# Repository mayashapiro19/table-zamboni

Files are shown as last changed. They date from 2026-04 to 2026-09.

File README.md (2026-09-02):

# Table Zamboni

## Hardware Block Diagram
The image below shows a high-level block diagram of the hardware architecture.<br>
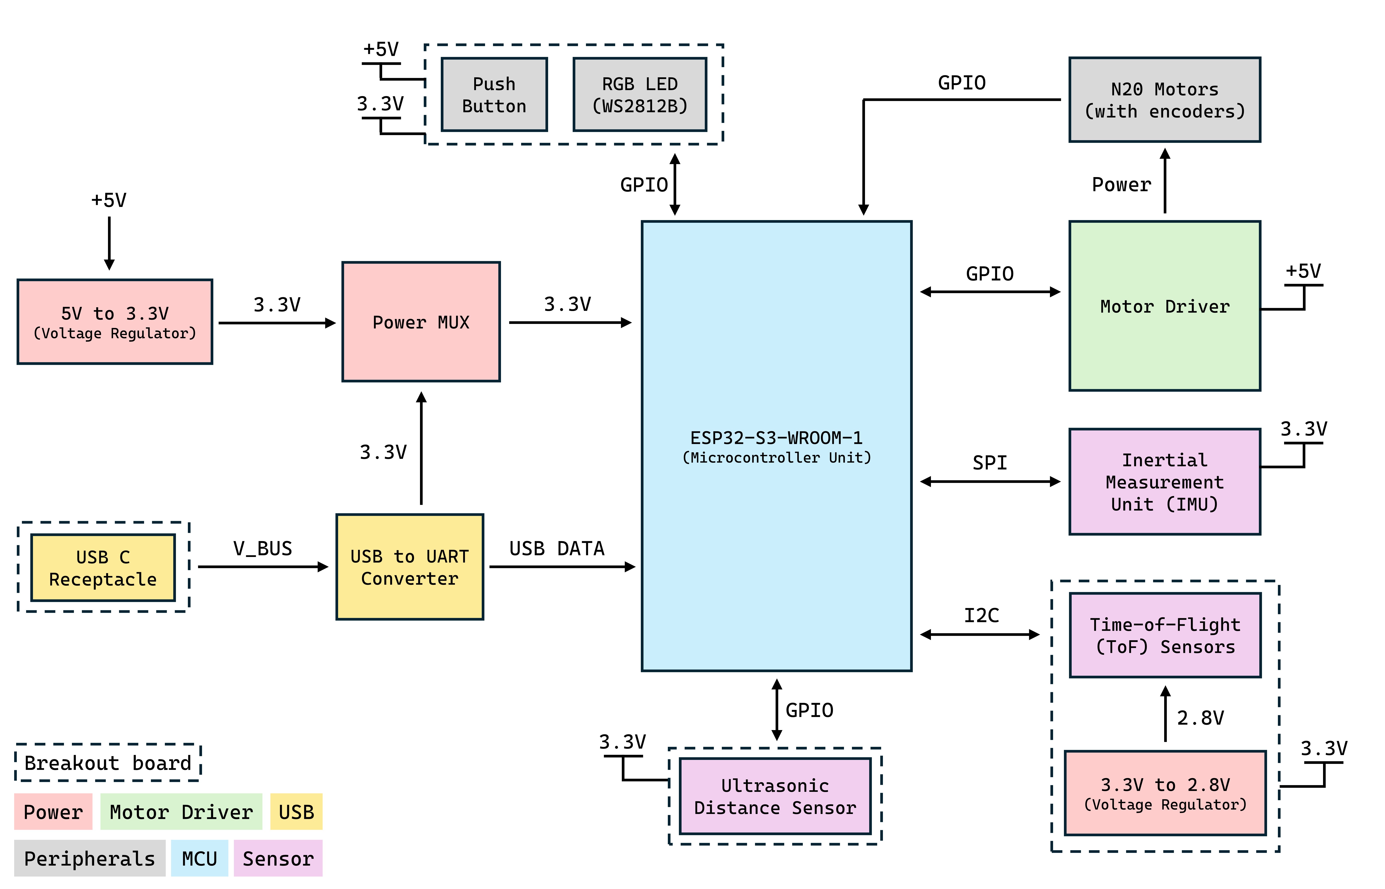
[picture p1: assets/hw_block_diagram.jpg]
Hardware Block Diagram


### Main PCB
The main PCB uses an ESP32-S3-WROOM-1-N8 module and includes power management circuitry, a USB to UART converter, motor driver, and an inertial measurement unit.

### Time-of-Flight Breakout Board

### Peripherals Breakout Board
The peripherals breakout board includes a push button and a WS2812B LED. The LED will be used at specific points to communicate things to the user. Because it will only be used for short periods of time, to save power, a load switch is used. The block diagram below illustrates the hardware architecture of the peripherals breakout board.<br>
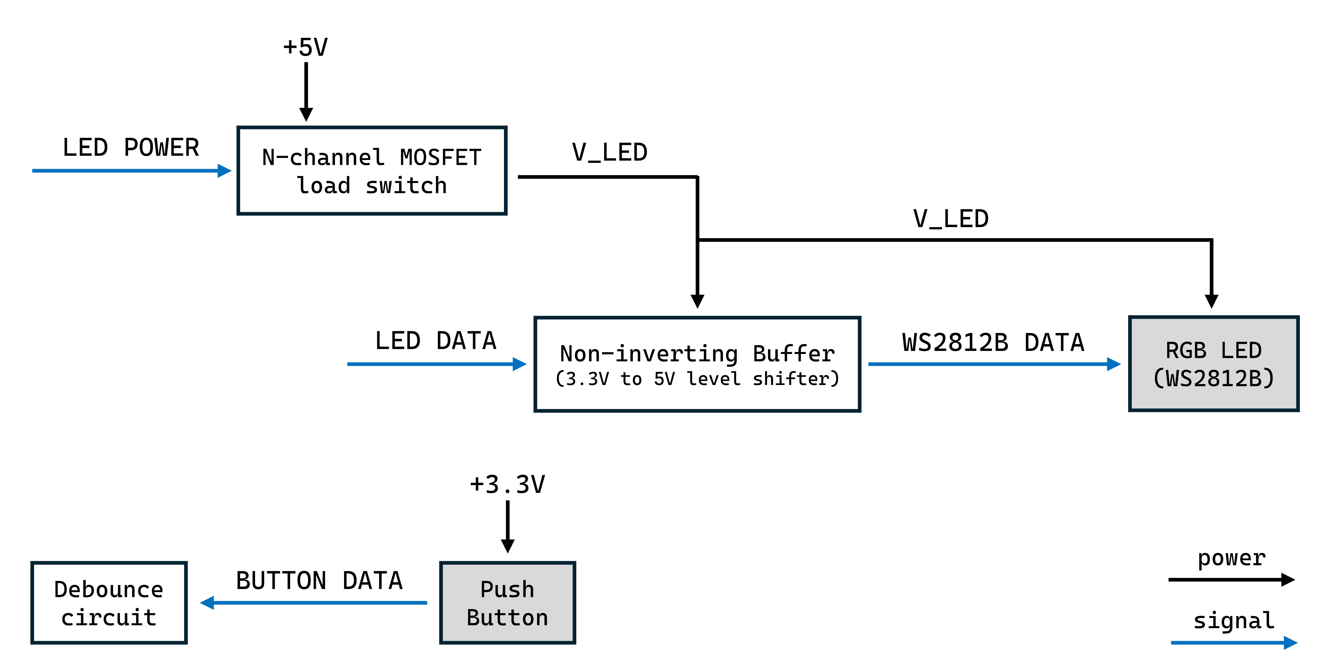
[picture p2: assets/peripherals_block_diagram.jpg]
Peripherals Breakout Board Block Diagram


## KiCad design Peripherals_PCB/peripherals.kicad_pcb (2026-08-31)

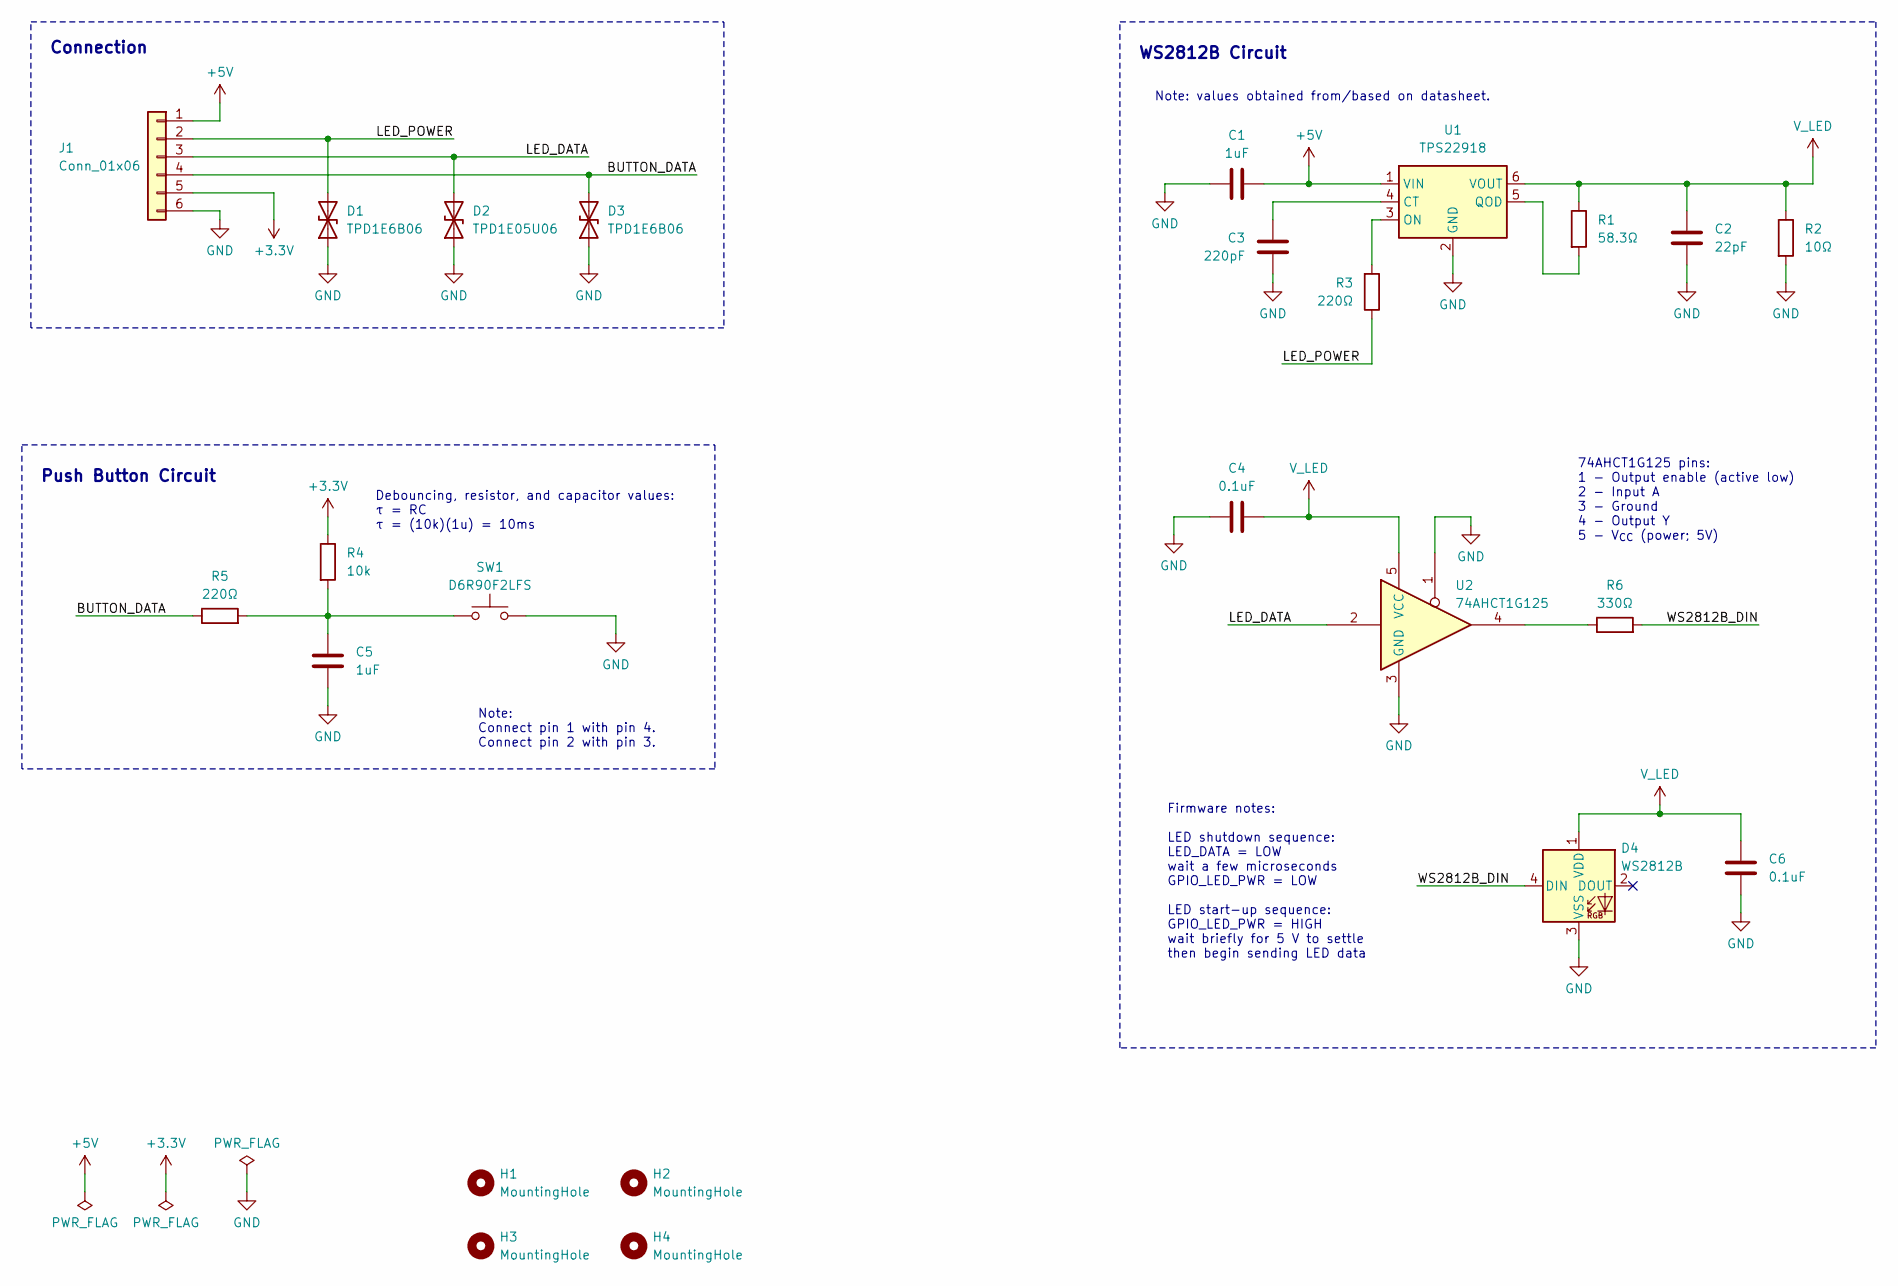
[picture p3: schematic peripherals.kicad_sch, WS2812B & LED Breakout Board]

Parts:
C1, C5: 1uF; C_0805_2012Metric_Pad1.18x1.45mm_HandSolder
C2: 22pF; C_0805_2012Metric_Pad1.18x1.45mm_HandSolder
C3: 220pF; C_0805_2012Metric_Pad1.18x1.45mm_HandSolder
C4, C6: 0.1uF; C_0805_2012Metric_Pad1.18x1.45mm_HandSolder
D1, D3: TPD1E6B06; TPD1E6B06_footprint
D2: TPD1E05U06
D4: WS2812B; COM-16347_SPK-M
H1, H2, H3, H4: MountingHole; MountingHole_3mm
J1: Conn_01x06; JST_SH_BM06B-SRSS-TB_1x06-1MP_P1.00mm_Vertical
R1: 58.3Ω; R_0805_2012Metric_Pad1.20x1.40mm_HandSolder
R2: 10Ω; R_0805_2012Metric_Pad1.20x1.40mm_HandSolder
R3, R5: 220Ω; R_0805_2012Metric_Pad1.20x1.40mm_HandSolder
R4: 10k; R_0805_2012Metric_Pad1.20x1.40mm_HandSolder
R6: 330Ω; R_0805_2012Metric_Pad1.20x1.40mm_HandSolder
SW1: D6R90F2LFS; D6R90_CNK
U1: TPS22918; DBV6_TEX-M
U2: 74AHCT1G125; DBV5-M

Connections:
+3.3V: J1.5, R4.1
+5V: C1.1, J1.1, U1.1 (VIN)
/BUTTON_DATA: D3.2 (A2), J1.4, R5.1
/LED_DATA: D2.2 (A2), J1.3, U2.2
/LED_POWER: D1.2 (A2), J1.2, R3.1
/WS2812B_DIN: D4.4 (DIN), R6.2
GND: C1.2, C2.1, C3.1, C4.1, C5.2, C6.2, D1.1 (A1), D2.1 (A1), D3.1 (A1), D4.3 (VSS), J1.6, R2.2, SW1.2, U1.2 (GND), U2.1, U2.3 (GND)
unnamed: C5.1, R4.2, R5.2, SW1.1
unnamed: R6.1, U2.4
unnamed: C3.2, U1.4 (CT)
unnamed: R3.2, U1.3 (ON)
unnamed: R1.2, U1.5 (QOD)
V_LED: C2.2, C4.2, C6.1, D4.1 (VDD), R1.1, R2.1, U1.6 (VOUT), U2.5 (VCC)

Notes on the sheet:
Note: Connect pin 1 with pin 4. Connect pin 2 with pin 3.
Debouncing, resistor, and capacitor values: τ = RC τ = (10k)(1u) = 10ms
WS2812B Circuit
Firmware notes: LED shutdown sequence: LED_DATA = LOW wait a few microseconds GPIO_LED_PWR = LOW LED start-up sequence: GPIO_LED_PWR = HIGH wait briefly for 5 V to settle then begin sending LED data
Push Button Circuit
Connection
74AHCT1G125 pins: 1 - Output enable (active low) 2 - Input A 3 - Ground 4 - Output Y 5 - V_{CC} (power; 5V)
Note: values obtained from/based on datasheet.

Board: 4 copper layers, 24 parts (2 on the bottom side), 13 nets, no tracks yet.

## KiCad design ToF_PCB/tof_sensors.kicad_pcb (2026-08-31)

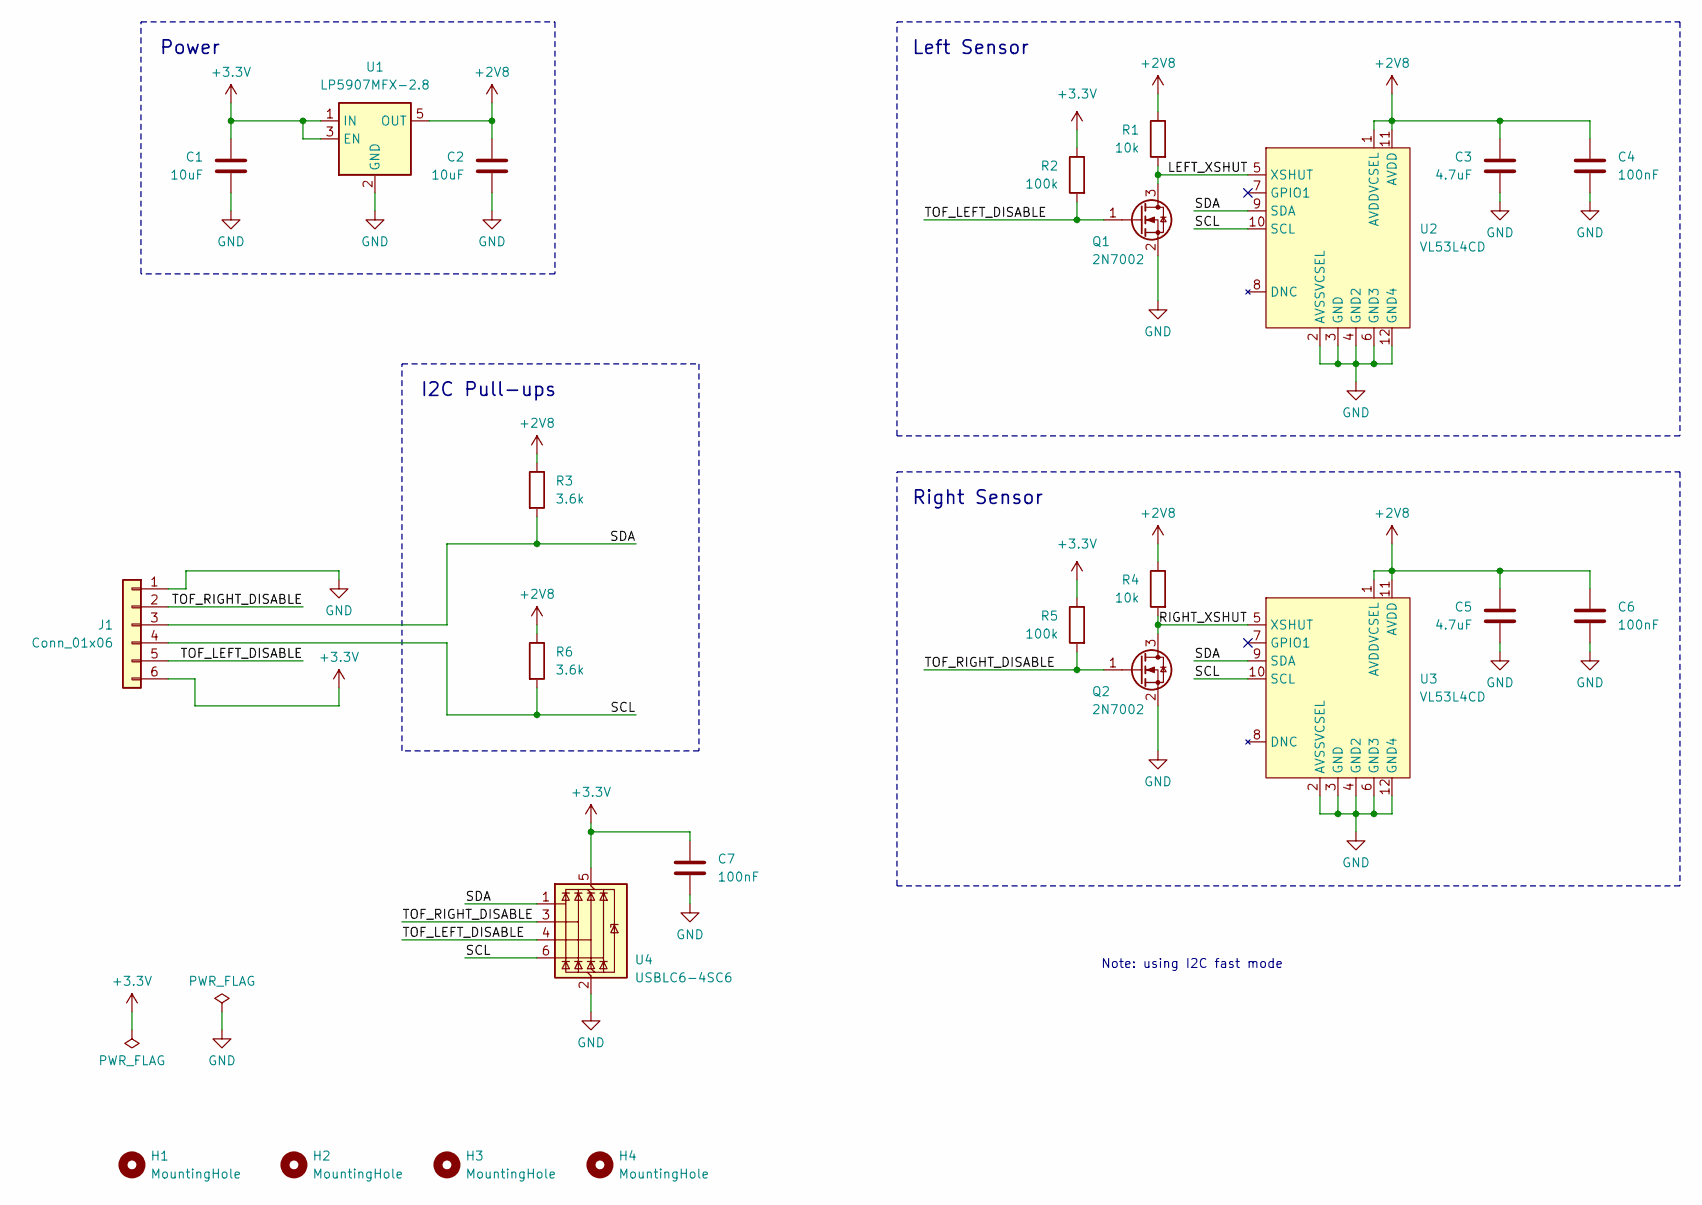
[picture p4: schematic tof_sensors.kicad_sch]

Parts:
C1: 10uF; C_0504_1310Metric
C2: 10uF; C_0805_2012Metric_Pad1.18x1.45mm_HandSolder
C3, C5: 4.7uF; C_0805_2012Metric_Pad1.18x1.45mm_HandSolder
C4, C6: 100nF; C_0805_2012Metric_Pad1.18x1.45mm_HandSolder
C7: 100nF; C_0201_0603Metric
H1, H2, H3, H4: MountingHole; MountingHole_2.5mm
J1: Conn_01x06; JST_SH_BM06B-SRSS-TB_1x06-1MP_P1.00mm_Vertical
Q1, Q2: 2N7002; SOT-23
R1, R4: 10k; R_0805_2012Metric_Pad1.20x1.40mm_HandSolder
R2, R5: 100k; R_0805_2012Metric_Pad1.20x1.40mm_HandSolder
R3, R6: 3.6k; R_0805_2012Metric_Pad1.20x1.40mm_HandSolder
U1: LP5907MFX-2.8; SOT-23-5
U2, U3: VL53L4CD
U4: USBLC6-4SC6; SOT-23-6

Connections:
+2V8: C2.1, C3.1, C4.1, C5.1, C6.1, R1.1, R3.1, R4.1, R6.1, U1.5 (OUT), U2.1 (AVDDVCSEL), U2.11 (AVDD), U3.1 (AVDDVCSEL), U3.11 (AVDD)
+3.3V: C1.1, C7.1, J1.6, R2.1, R5.1, U1.1 (IN), U1.3 (EN), U4.5 (VBUS)
/LEFT_XSHUT: Q1.3 (D), R1.2, U2.5 (XSHUT)
/RIGHT_XSHUT: Q2.3 (D), R4.2, U3.5 (XSHUT)
/SCL: J1.4, R6.2, U2.10 (SCL), U3.10 (SCL), U4.6 (I/O4)
/SDA: J1.3, R3.2, U2.9 (SDA), U3.9 (SDA), U4.1 (I/O1)
/TOF_LEFT_DISABLE: J1.5, Q1.1 (G), R2.2, U4.4 (I/O3)
/TOF_RIGHT_DISABLE: J1.2, Q2.1 (G), R5.2, U4.3 (I/O2)
GND: C1.2, C2.2, C3.2, C4.2, C5.2, C6.2, C7.2, J1.1, Q1.2 (S), Q2.2 (S), U1.2 (GND), U2.2 (AVSSVCSEL), U2.3 (GND), U2.4 (GND2), U2.6 (GND3), U2.12 (GND4), U3.2 (AVSSVCSEL), U3.3 (GND), U3.4 (GND2), U3.6 (GND3), U3.12 (GND4), U4.2 (GND)

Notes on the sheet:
Left Sensor
Power
I2C Pull-ups
Right Sensor
Note: using I2C fast mode

Board: 4 copper layers, 24 parts (2 on the bottom side), 9 nets, no tracks yet.

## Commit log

2026-07-21 Delete motor_driver_circuit.kicad_sch
    Deleting file
    [motor_driver_circuit.kicad_sch]
2026-07-21 Removing old files that were added by mistake."
    [motor_driver_circuit.kicad_sch]
2026-07-21 Adding root page of schematic using esp32-wroom-32e
    [table-zamboni.kicad_sch]
2026-07-21 Adding 'subcircuits' of schematic using esp32-wroom-32e
    [drive_motors.kicad_sch, esp32.kicad_sch, navigation_sensors.kicad_sch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]
2026-07-27 Adding main pcb schematic. Still need to remove battery from schematic as battery will have seperate pcb.
    [drive_motors.kicad_sch, esp32.kicad_sch, imu.kicad_sch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]
2026-07-27 Delete drive_motors.kicad_sch
    Removing previous version
    [drive_motors.kicad_sch]
2026-07-27 Delete esp32.kicad_sch
    Removing previous version of file from branch
    [esp32.kicad_sch]
2026-07-27 Delete navigation_sensors.kicad_sch
    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
    [navigation_sensors.kicad_sch]
2026-07-27 Delete pwr_mgmt.kicad_sch
    Removing previous version of files from branch
    [pwr_mgmt.kicad_sch]
2026-07-27 Delete table-zamboni.kicad_pcb
    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
    [table-zamboni.kicad_pcb]
2026-07-27 Delete table-zamboni.kicad_sch
    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
    [table-zamboni.kicad_sch]
2026-07-27 Delete table-zamboni.kicad_pro
    Removing from branch due to changed folder structure
2026-07-30 First draft of schematic complete. Still need to verify it is correct before proceeding to pcb.
    [drive_motors.kicad_sch, esp32.kicad_sch, imu.kicad_sch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]
2026-07-30 Delete table-zamboni.kicad_pcb
    Removing old empty file.
    [table-zamboni.kicad_pcb]
2026-07-30 Delete table-zamboni.kicad_pro
    Removing old empty file
2026-07-30 Delete table-zamboni.kicad_sch
    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
    [table-zamboni.kicad_sch]
2026-07-30 Delete ~table-zamboni.kicad_sch.lck
    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
2026-08-02 Added decoupling capacitors, pulldown resistors, test points, and more. Still need to finish verifying schematic before PCB layout.
    [drive_motors.kicad_sch, pwr_mgmt.kicad_sch, table-zamboni.kicad_sch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]
2026-08-02 Adding most recent version of schematic. I have now decided to use NiMH batteries instead of Li-ion because they are safer and I don't want to start a fire.
    [drive_motors.kicad_sch, pwr_mgmt.kicad_sch, tof_sensors.kicad_sch]
2026-08-22 Adding schematic and pcb layout before routing.
    [tof_sensors.kicad_pcb, tof_sensors.kicad_sch]
2026-08-22 Added layers and fixed layout + shape of pcb. Going to add esd protection now so pushing changes before doing so.
    [tof_sensors.kicad_pcb]
2026-08-27 Updated pcb layout. Moved ToF sensors to back of board.
    [tof_sensors.kicad_pcb, tof_sensors.kicad_sch]
2026-08-31 Adding changes. Changes made to cleanup schematic before pcb layout.
    [drive_motors.kicad_sch, imu.kicad_sch, pwr_mgmt.kicad_sch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]
2026-08-31 Adding schematic and layout of peripherals board with ws2812b led and push button.
    [peripherals.kicad_pcb, peripherals.kicad_sch]
2026-09-01 Removed MOSFET circuit from power management subsystem.
    [pwr_mgmt.kicad_sch]
